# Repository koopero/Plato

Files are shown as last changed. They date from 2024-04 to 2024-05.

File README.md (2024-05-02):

# Project Plato

The goal is the creation of a full set of all 5 regular polyhedra, or Platonic Solids, using programmable LEDs and 3D printed plastic.

- Open-source hardware & software.
- AI-assisted programming and design practices.
- Iteratative & improvisational design processes.
- Parametric practical geometry. 
- PCB design using Kicad

# Subprojects

|Project|Description|Status|
|---|---|---|
|[Plato_A2](Plato_A2/README.md)|Triangular LED board|Awaiting manufacture|
|[Plato_A1](Plato_A1/README.md)|Triangular LED board|Failed testing|
|[Plato_B1](Plato_B1/README.md)|ESP32 control board|In-progress|
|[Plato_C1](Plato_C1/README.md)|Tetrahedron casing for Plato_A1|Success|

# Tooling

- Kicad
- Python
- ImageMagick
- OpenSCAD
- Blender

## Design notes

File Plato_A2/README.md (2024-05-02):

# Plato_A2

*Please note that this design has failed testing and should not be used.*

`Plato_A2` is a regular triangle, made of light and plastic, with a dimension of about an inch. This subassembly is meant as an experiment in:

|Spec|Value|Unit|
|----|-----|----|
|LED Count| 28 | WS2812B 2020|

# Process

- Iterate design scripts from `Plato_A1` ( `Plato_A2_design.py` and `kicad_align_leds.py` )
  - Better LED orientation.
  - Export of holes and jumpers.
  - Placement of capacitors.
- Start a new project in Kicad
- Create schematic with all parts.
- Switch to PCB designer and import generated file `Plato_A2_board.dxf` into edge cut layer.
- Copy and paste the script `kicad_align_leds.py` into Kicad's scripting console to position LEDs.
- Manually place bulk capacitors and resistor.
- Draw routes to connect all components, using vias beneath LEDs.
- Create wicked silkscreen for front.
  - Create `art/Plato_A2_Art.png` in Gimp
  - Import png to Inkscape
  - *Trace Bitmap* with *Color Quantization*
  - *Path / Break Apart*
  - Delete image and background shape
  - Export to `art/Plato_A2_Art.dxf`
  - Import to kicad silkscreen layer.
  - Manually delete overlaps after DRC.
- Run DRC and fix problems.
- Use Kicad's Fabrication Toolkit plugin to aid in preparing the board for fabrication.
- Use [JLCPCB](https://jlcpcb.com/)'s online tools to order 5 copies of the board.

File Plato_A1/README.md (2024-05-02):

# Plato_A1

*Please note that this design has failed testing and should not be used.*

`Plato_A1` is a regular triangle, made of light and plastic, with a dimension of about an inch. This subassembly is meant as an experiment in:

- **Parametric Geometry** : The layout and dimensions of the PCB are defined in python.
- **Electronic Basics** : Learn Kicad by doing.
- **LED placement** : The triangular shape of the piece makes cartesian component alignment unfeasible. Therfore, the LEDs are align in a triagnular grid. Additionally, the LEDs are oriented towards the centre of the piece, for aesthetics and to diffuse potential chromatric anisotropy.

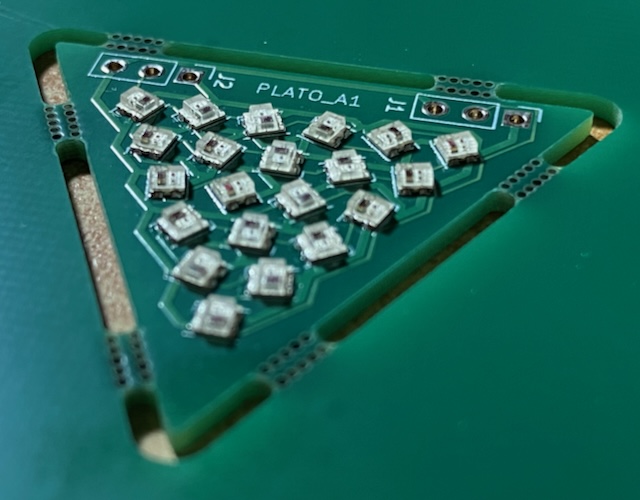
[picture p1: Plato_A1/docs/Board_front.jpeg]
Front of board

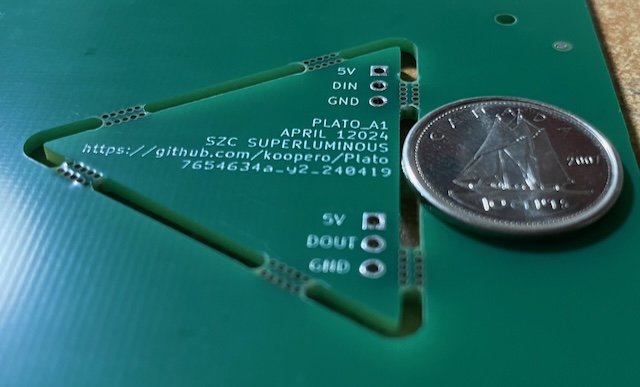
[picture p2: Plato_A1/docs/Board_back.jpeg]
Back of board


## Process

- Collaborate with ChapGPT & Copilot to prototype design generation scripts ( `Plato_A1_design.py` and `kicad_align_leds.py` )
- Tune parameters in design script to taste.
- Start a new project in Kicad
- Design circuit schematic in Kicad, consisting of 21 WS2812B 2020 LEDs and 2 3-pin jumper connectors. Ensure that all LEDs are sequentially named in the format `D1` to `D21`.
- Switch to PCB designer and import generated file `Plato_A1_board.dxf` into edge cut layer.
- Copy and paste the script `kicad_align_leds.py` into Kicad's scripting console to position LEDs.
- Manually place the jumper connectors.
- Draw routes to connect all components. Some LEDs are rotated in 90 degree increments for better connectivity.
- Add text and graphics the back silkscreen.
- Use Kicad's Fabrication Toolkit plugin to aid in preparing the board for fabrication.
- Use [JLCPCB](https://jlcpcb.com/)'s online tools to order 5 copies of the board.

## Result

Customer experience ordering from JLCPCB was exemplary. Representatives followed up for confirmation of the circuit's polarity (understandable given the non-traditional nature of the design).

Total cost for PCB manufacturing, assembly and shipping was about $100CAD. 

After unboxing, a quick test rig was produced, consisting of 3 jumper wires connected to a generic ESP32 Devkit V1, powered by USB. [WLED](https://install.wled.me/) was installed to produce a WS2811 signal.

Upon testing, the boards failed to maintain a coherent LED signal. About half the lamps will respond to a signal, but their performance is intermittent. By the end of the chain, the signal is lost completely.

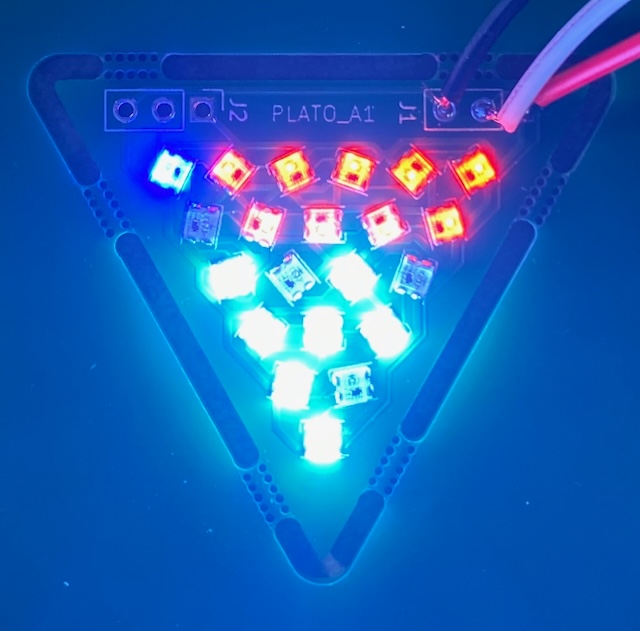
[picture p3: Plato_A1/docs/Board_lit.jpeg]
Front of board


## Lessons Learned

- PCB fabrication and assembly is a painless and relatively inexpensive process.
- Use power and ground planes in designing future PCBs.
- Decoupling capacitors and noise-supressing resistors will be necessary in subsequent designs.
- The chromatic anisotropy of WS2812B 2020 is much less pronounced than 5050 versions. Fun geometric placement will be de-prioritized in future version.
- Don't forget to choose the PCB colour when ordering!

## Next Steps

- Add through hole capacitors in attempt to stabilize boards.
- Assemble sample boards with Plato_C1 casing to demonstrate an illuminated, if uncontrolled, tetrahedron.
- Assemble content pertaining to creation of object.
- Research reference designs for WS2812B 2020 circuit boards.
- Design `Plato_A2` with similar dimensions and specifications, incorporating better electronic practices.

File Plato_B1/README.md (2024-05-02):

# Features

- ESP32-WROOM-32 Dual Core
- 

*After years of stringing together ESP32 Devkits, on breadboards and in boxes, I have decided to build.**

- MPU6050 accelerometer & gyro with independant i2c bus. 
- MicroUSB programming port (no charging).
- 4x exposed GPIO pins, each with accompanying 5V, and GND.
- 4x WS2812B 2020 LEDs, acting as both status display and signal booster. 
- 4x LED pin sets, with power from 5V or VBAT.
- Beefy 2A 5V buck converter, intended to run from 2S+ battery.
- Connection for external power switch.
- 6 pin auxillary connector with power & i2c.

At the end of the board

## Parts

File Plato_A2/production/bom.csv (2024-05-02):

Designator | Footprint | Quantity | Value | LCSC Part #
C1, C10, C11, C12, C13, C14, C15, C16, C17, C18, C19, C2, C20, C21, C22, C23, C24, C25, C26, C27, C28, C3, C4, C5, C6, C7, C8, C9 | 0402 | 28 | 100nF | C1525
C29, C30, C31 | 0603 | 3 | 10uF | C96446
D1, D10, D11, D12, D13, D14, D15, D16, D17, D18, D19, D2, D20, D21, D22, D23, D24, D25, D26, D27, D28, D3, D4, D5, D6, D7, D8, D9 | Plato_WS2812B-2020 | 28 | WS2812B-2020 | C965555
R1 | 0402 | 1 | 330ohm | C25104

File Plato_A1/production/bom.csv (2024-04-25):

Designator | Footprint | Quantity | Value | LCSC Part #
D1, D10, D11, D12, D13, D14, D15, D16, D17, D18, D19, D2, D20, D21, D3, D4, D5, D6, D7, D8, D9 | LED_WS2812B-2020_PLCC4_2.0x2.0mm | 21 | WS2812B-2020

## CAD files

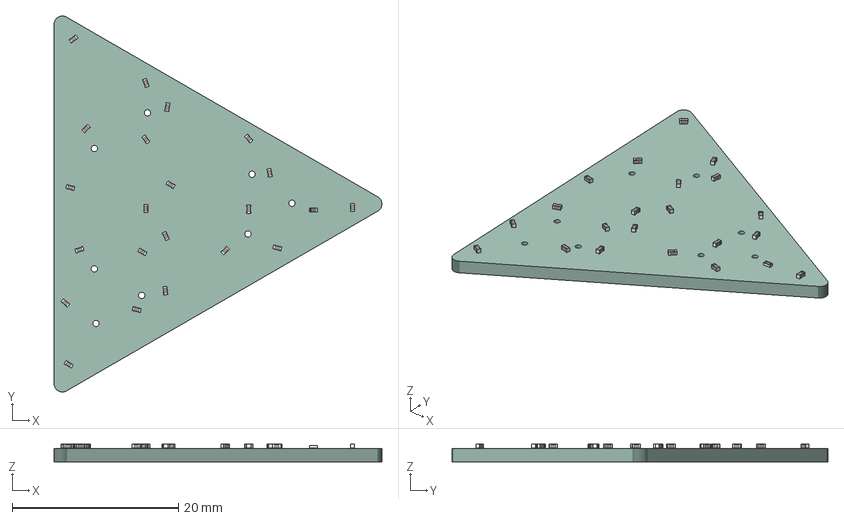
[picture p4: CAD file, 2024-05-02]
Plato_A1/output/Plato_A1.step
39.5 x 45.3 x 2.15 mm
R_0402_1005Metric
C_0402_1005Metric x 21
_autosave-Plato_A1_PCB

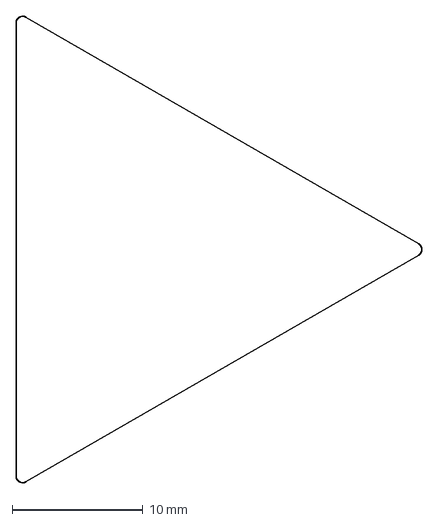
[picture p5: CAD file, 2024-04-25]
Plato_A1/Plato_A1_Board.dxf
31.0 x 35.6 mm

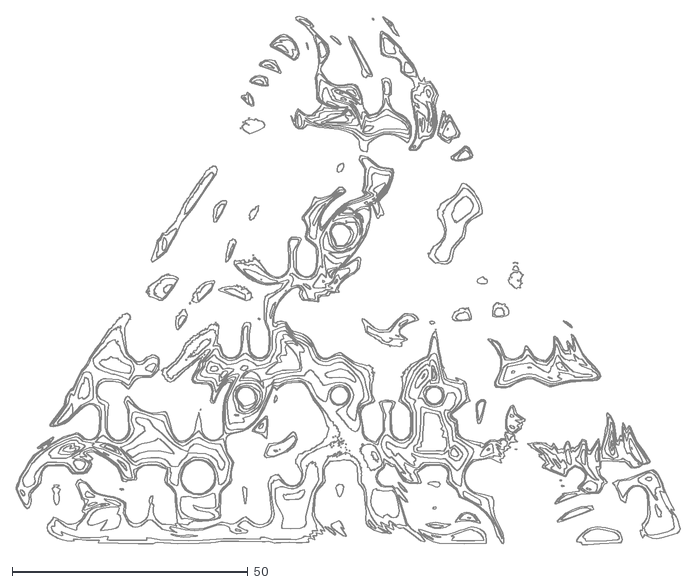
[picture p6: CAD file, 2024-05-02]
Plato_A2/art/Plato_A2_Art.dxf
140.7 x 111.9

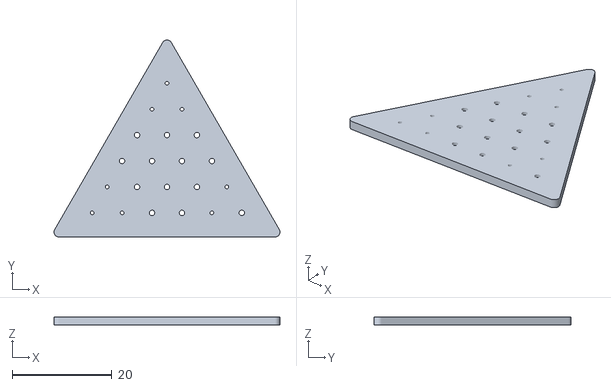
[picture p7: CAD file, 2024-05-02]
Plato_A2/output/Plato_A2_board.stl
45.3 x 39.5 x 1.60

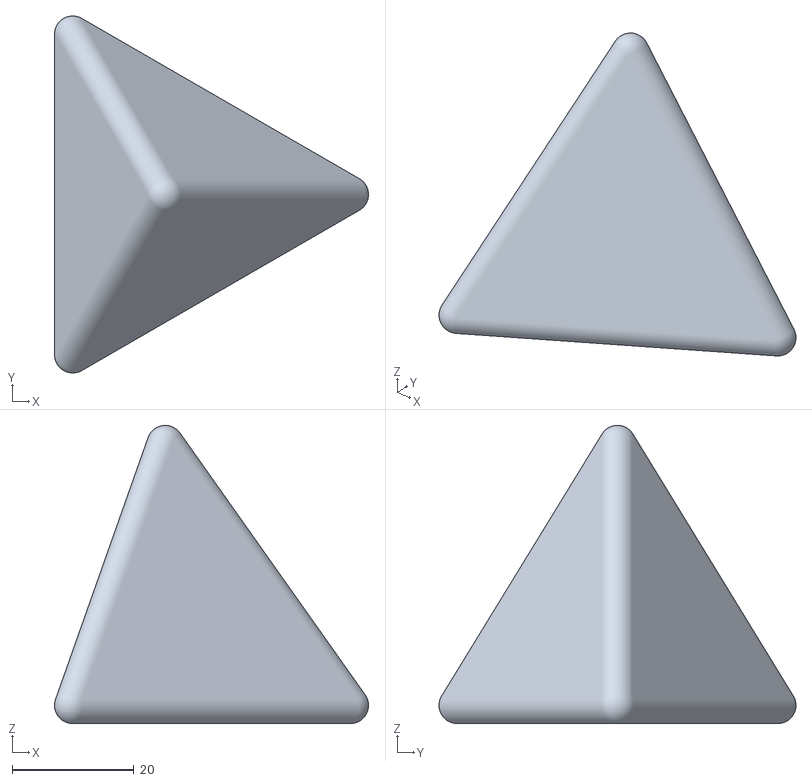
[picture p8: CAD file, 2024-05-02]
Plato_C1/Plato_C1_Tetra.stl
51.7 x 58.8 x 49.1

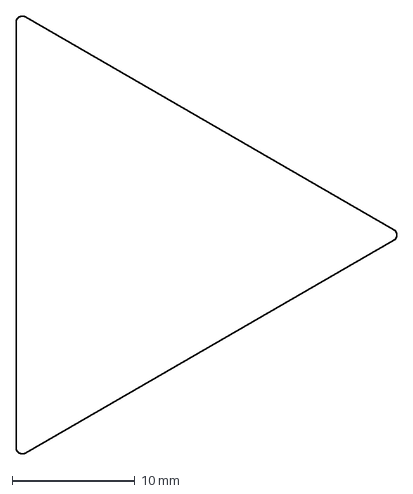
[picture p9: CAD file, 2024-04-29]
Plato_A1/output/Plato_A1_Board.dxf
31.0 x 35.6 mm

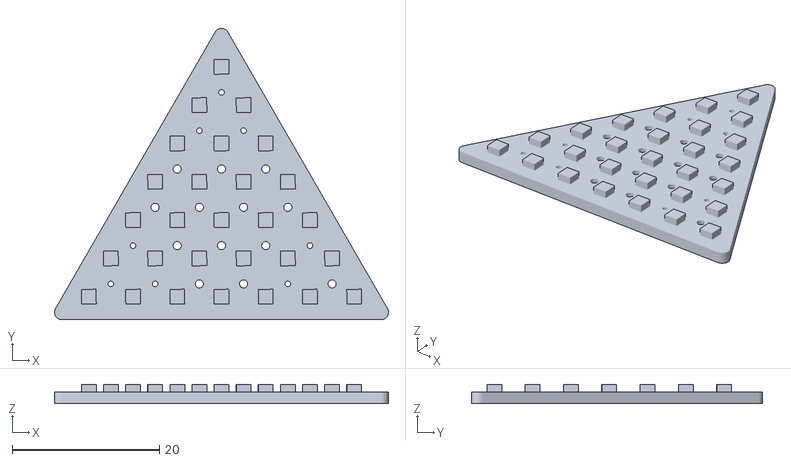
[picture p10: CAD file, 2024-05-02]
Plato_A2/output/Plato_A2.stl
45.3 x 39.5 x 2.60

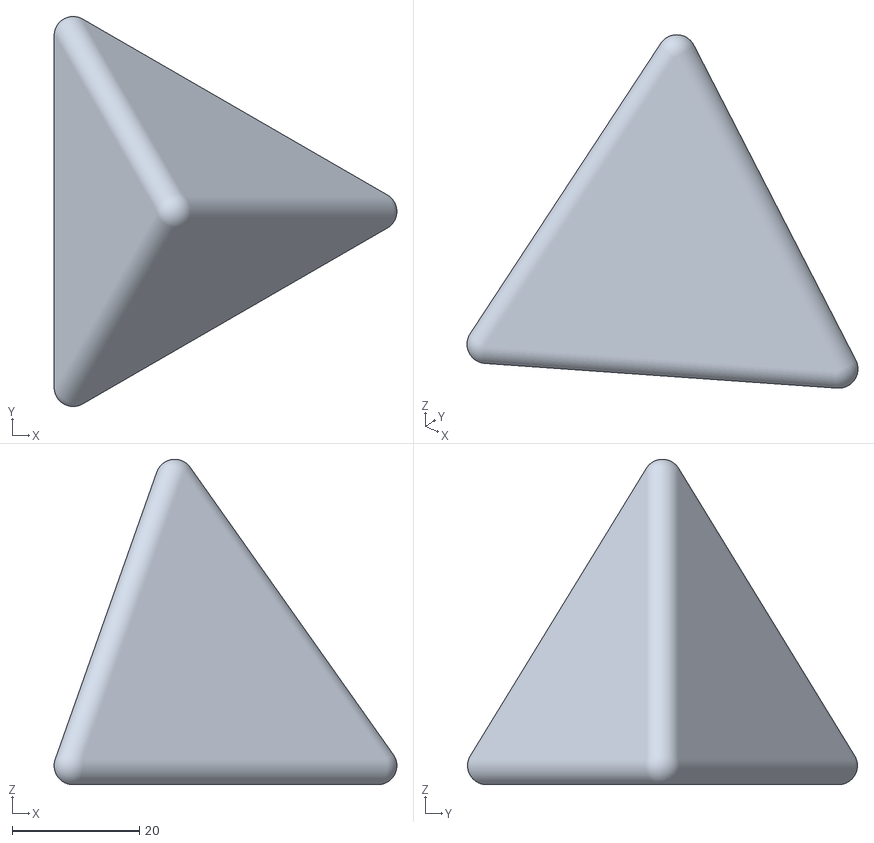
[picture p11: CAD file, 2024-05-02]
Plato_C1/Plato_C1.stl
53.9 x 61.3 x 51.2

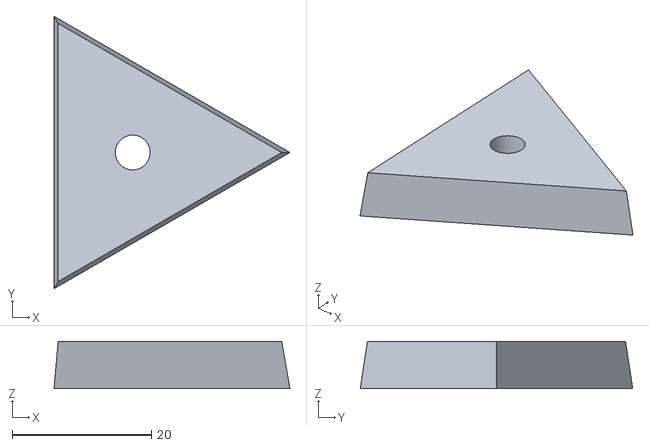
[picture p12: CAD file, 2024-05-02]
Plato_C1/Plato_C1_Cap.stl
33.9 x 39.1 x 6.82

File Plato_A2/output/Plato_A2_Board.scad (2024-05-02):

use <../library.scad>;
difference() {
   triangle_board( 27, 1, 1.6);
   hole(0.0, 17.320508075688775, 0.38);
   hole(-3.0, 12.12435565298214, 0.38);
   hole(3.0, 12.12435565298214, 0.38);
   hole(6.0, 6.928203230275509, 0.55);
   hole(0.0, 6.928203230275509, 0.55);
   hole(-6.0, 6.928203230275509, 0.55);
   hole(-9.0, 1.7320508075688772, 0.55);
   hole(-3.0, 1.7320508075688772, 0.55);
   hole(3.0, 1.7320508075688772, 0.55);
   hole(9.0, 1.7320508075688772, 0.55);
   hole(12.0, -3.464101615137755, 0.38);
   hole(6.0, -3.464101615137755, 0.55);
   hole(0.0, -3.464101615137755, 0.55);
   hole(-6.0, -3.464101615137755, 0.55);
   hole(-12.0, -3.464101615137755, 0.38);
   hole(-15.0, -8.660254037844387, 0.38);
   hole(-9.0, -8.660254037844387, 0.38);
   hole(-3.0, -8.660254037844387, 0.55);
   hole(3.0, -8.660254037844387, 0.55);
   hole(9.0, -8.660254037844387, 0.38);
   hole(15.0, -8.660254037844387, 0.55);
}

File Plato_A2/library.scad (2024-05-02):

$fs = 0.1;
$fa = 0.1;

module triangle_board( point_radius = 24, roundness = 1, extrusion = 1.6 ) {
    color([0.3,0.3,0.3])
    linear_extrude(height = extrusion, center = false)
    offset(r = roundness, chamfer = false) 
    offset(r = -roundness, chamfer = false) 
    polygon(points=[
        [-sin(60)*point_radius, -cos(60)* point_radius], // First vertex at origin
        [sin(60)*point_radius, -cos(60)* point_radius], // First vertex at origin
        [0, point_radius] // Third vertex at top center
    ]);
}

module hole(x, y, radius) {
    translate([x, y, 0])  // Move the cylinder to the (x, y) position
    cylinder(h = 100, r = radius, center = true);
}

module led(x, y, orientation, z = 1.6) {
    color("white", 1)
    translate([x, y, z+0.5])
    rotate([0, 0, orientation])
    cube([2, 2, 1], center = true);
}

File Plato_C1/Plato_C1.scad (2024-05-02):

// Define vertices of the regular tetrahedron
vertices = [
    [ 0,  0,  2],  // Vertex 0
    [-cos(60)*1,  -sin(60)*1, 0],  // Vertex 1
    [-cos(60)*1,  sin(60)*1, 0],  // Vertex 2
    [ 1,  0, 0]   // Vertex 3
];

// Define faces using the vertices
faces = [
    [0, 1, 2], // Face 1
    [0, 3, 1], // Face 2
    [0, 2, 3], // Face 3
    [1, 3, 2]  // Face 4
];



// Create the regular tetrahedron
polyhedron(points = vertices, faces = faces);

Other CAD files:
Plato_A2/output/Plato_A2.scad
Plato_A2/output/Plato_A2_Board.dxf

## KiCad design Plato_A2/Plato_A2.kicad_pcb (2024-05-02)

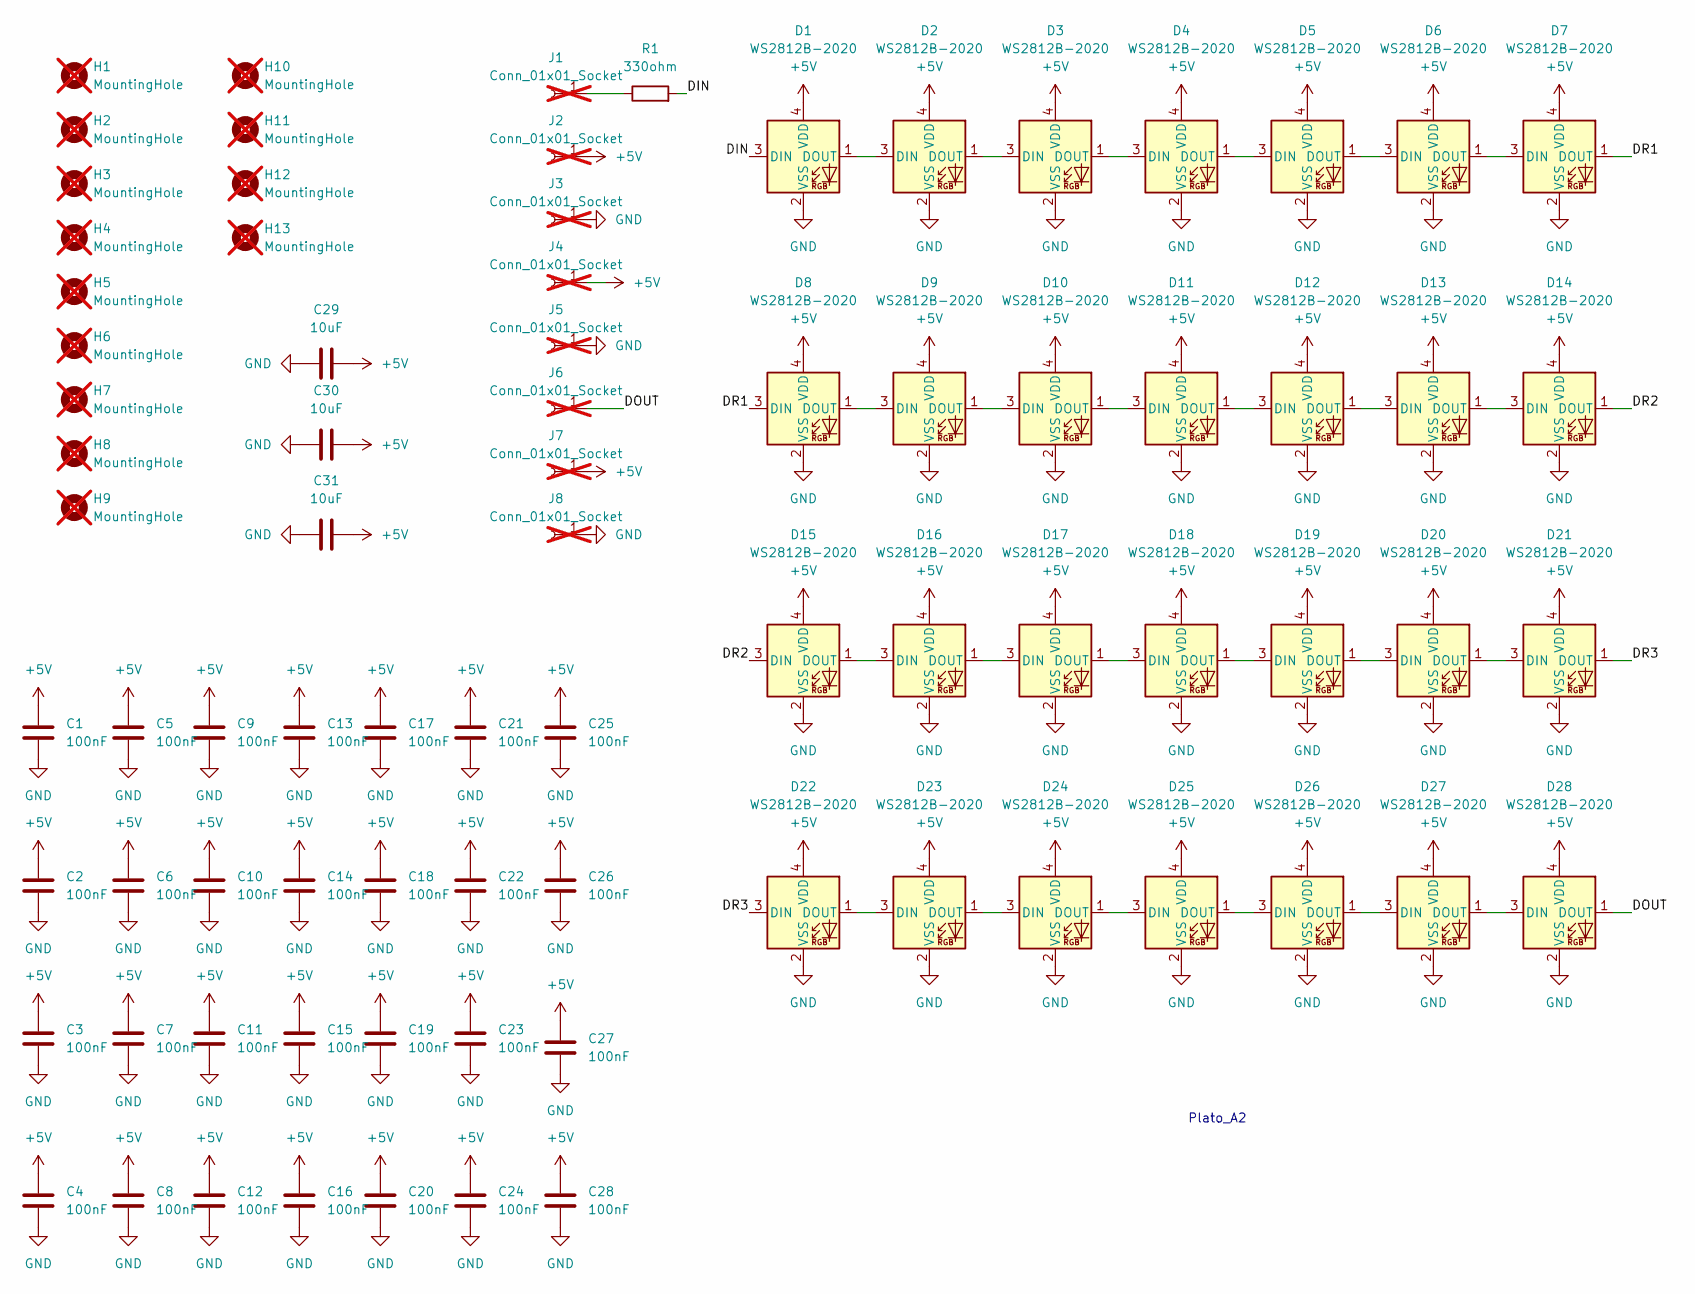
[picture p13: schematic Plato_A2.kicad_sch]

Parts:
C1, C2, C3, C4, C5, C6, C7, C8, C9, C10, C11, C12, C13, C14, C15, C16, C17, C18, C19, C20, C21, C22, C23, C24, C25, C26, C27, C28: 100nF; C_0402_1005Metric; LCSC C1525
C29, C30, C31: 10uF; C_0603_1608Metric; LCSC C96446
D1, D2, D3, D4, D5, D6, D7, D8, D9, D10, D11, D12, D13, D14, D15, D16, D17, D18, D19, D20, D21, D22, D23, D24, D25, D26, D27, D28: WS2812B-2020; Plato_WS2812B-2020; LCSC C965555
H1, H2, H3, H4, H5, H6, H7, H8, H9, H10, H11, H12, H13: MountingHole; MountingHoleM1; not fitted
J1, J6: Conn_01x01_Socket; DataHole; not fitted
J2, J3, J4, J5, J7, J8: Conn_01x01_Socket; PowerHole; not fitted
R1: 330ohm; R_0402_1005Metric; LCSC C25104

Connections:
+5V: C1.1, C2.1, C3.1, C4.1, C5.1, C6.1, C7.1, C8.1, C9.1, C10.1, C11.1, C12.1, C13.1, C14.1, C15.1, C16.1, C17.1, C18.1, C19.1, C20.1, C21.1, C22.1, C23.1, C24.1, C25.1, C26.1, C27.1, C28.1, C29.2, C30.2, C31.2, D1.4 (VDD), D2.4 (VDD), D3.4 (VDD), D4.4 (VDD), D5.4 (VDD), D6.4 (VDD), D7.4 (VDD), D8.4 (VDD), D9.4 (VDD), D10.4 (VDD), D11.4 (VDD), D12.4 (VDD), D13.4 (VDD), D14.4 (VDD), D15.4 (VDD), D16.4 (VDD), D17.4 (VDD), D18.4 (VDD), D19.4 (VDD), D20.4 (VDD), D21.4 (VDD), D22.4 (VDD), D23.4 (VDD), D24.4 (VDD), D25.4 (VDD), D26.4 (VDD), D27.4 (VDD), D28.4 (VDD), J2.1, J4.1, J7.1
/DIN: D1.3 (DIN), R1.2
/DOUT: D28.1 (DOUT), J6.1
/DR1: D7.1 (DOUT), D8.3 (DIN)
/DR2: D14.1 (DOUT), D15.3 (DIN)
/DR3: D21.1 (DOUT), D22.3 (DIN)
GND: C1.2, C2.2, C3.2, C4.2, C5.2, C6.2, C7.2, C8.2, C9.2, C10.2, C11.2, C12.2, C13.2, C14.2, C15.2, C16.2, C17.2, C18.2, C19.2, C20.2, C21.2, C22.2, C23.2, C24.2, C25.2, C26.2, C27.2, C28.2, C29.1, C30.1, C31.1, D1.2 (VSS), D2.2 (VSS), D3.2 (VSS), D4.2 (VSS), D5.2 (VSS), D6.2 (VSS), D7.2 (VSS), D8.2 (VSS), D9.2 (VSS), D10.2 (VSS), D11.2 (VSS), D12.2 (VSS), D13.2 (VSS), D14.2 (VSS), D15.2 (VSS), D16.2 (VSS), D17.2 (VSS), D18.2 (VSS), D19.2 (VSS), D20.2 (VSS), D21.2 (VSS), D22.2 (VSS), D23.2 (VSS), D24.2 (VSS), D25.2 (VSS), D26.2 (VSS), D27.2 (VSS), D28.2 (VSS), J3.1, J5.1, J8.1
unnamed: D1.1 (DOUT), D2.3 (DIN)
unnamed: D2.1 (DOUT), D3.3 (DIN)
unnamed: D3.1 (DOUT), D4.3 (DIN)
unnamed: D4.1 (DOUT), D5.3 (DIN)
unnamed: D5.1 (DOUT), D6.3 (DIN)
unnamed: D6.1 (DOUT), D7.3 (DIN)
unnamed: D8.1 (DOUT), D9.3 (DIN)
unnamed: D9.1 (DOUT), D10.3 (DIN)
unnamed: D10.1 (DOUT), D11.3 (DIN)
unnamed: D11.1 (DOUT), D12.3 (DIN)
unnamed: D12.1 (DOUT), D13.3 (DIN)
unnamed: D13.1 (DOUT), D14.3 (DIN)
unnamed: D15.1 (DOUT), D16.3 (DIN)
unnamed: D16.1 (DOUT), D17.3 (DIN)
unnamed: D17.1 (DOUT), D18.3 (DIN)
unnamed: D18.1 (DOUT), D19.3 (DIN)
unnamed: D19.1 (DOUT), D20.3 (DIN)
unnamed: D20.1 (DOUT), D21.3 (DIN)
unnamed: D22.1 (DOUT), D23.3 (DIN)
unnamed: D23.1 (DOUT), D24.3 (DIN)
unnamed: D24.1 (DOUT), D25.3 (DIN)
unnamed: D25.1 (DOUT), D26.3 (DIN)
unnamed: D26.1 (DOUT), D27.3 (DIN)
unnamed: D27.1 (DOUT), D28.3 (DIN)
unnamed: J1.1, R1.1

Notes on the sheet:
Plato_A2

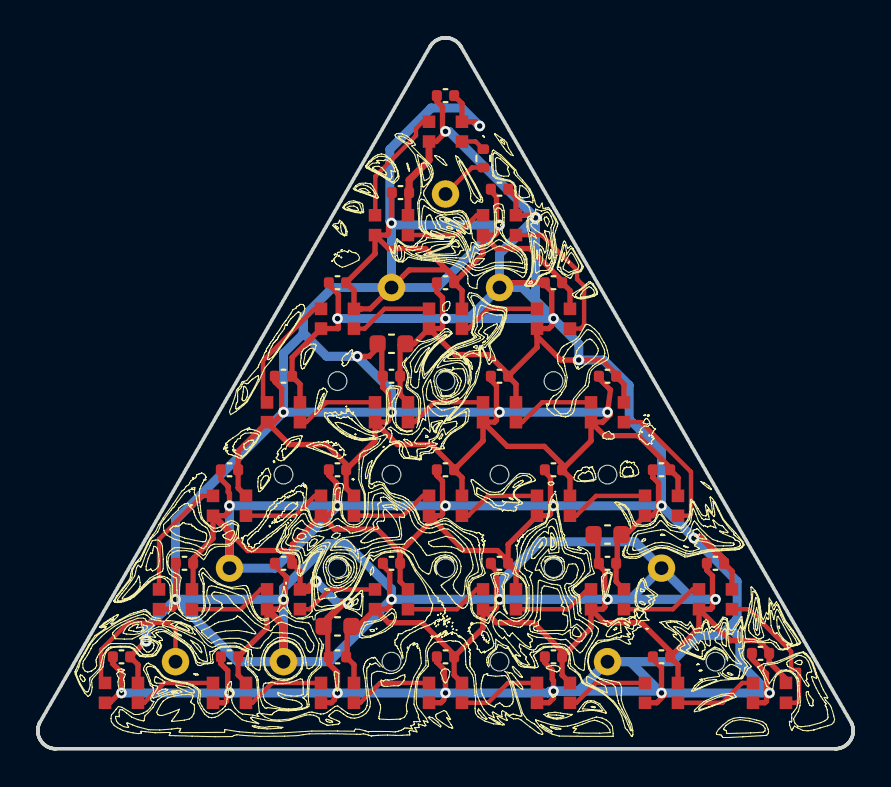
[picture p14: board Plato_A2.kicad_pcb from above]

Board: 2 copper layers, 45.3 x 39.5 mm, 81 parts (0 on the bottom side), 32 nets.

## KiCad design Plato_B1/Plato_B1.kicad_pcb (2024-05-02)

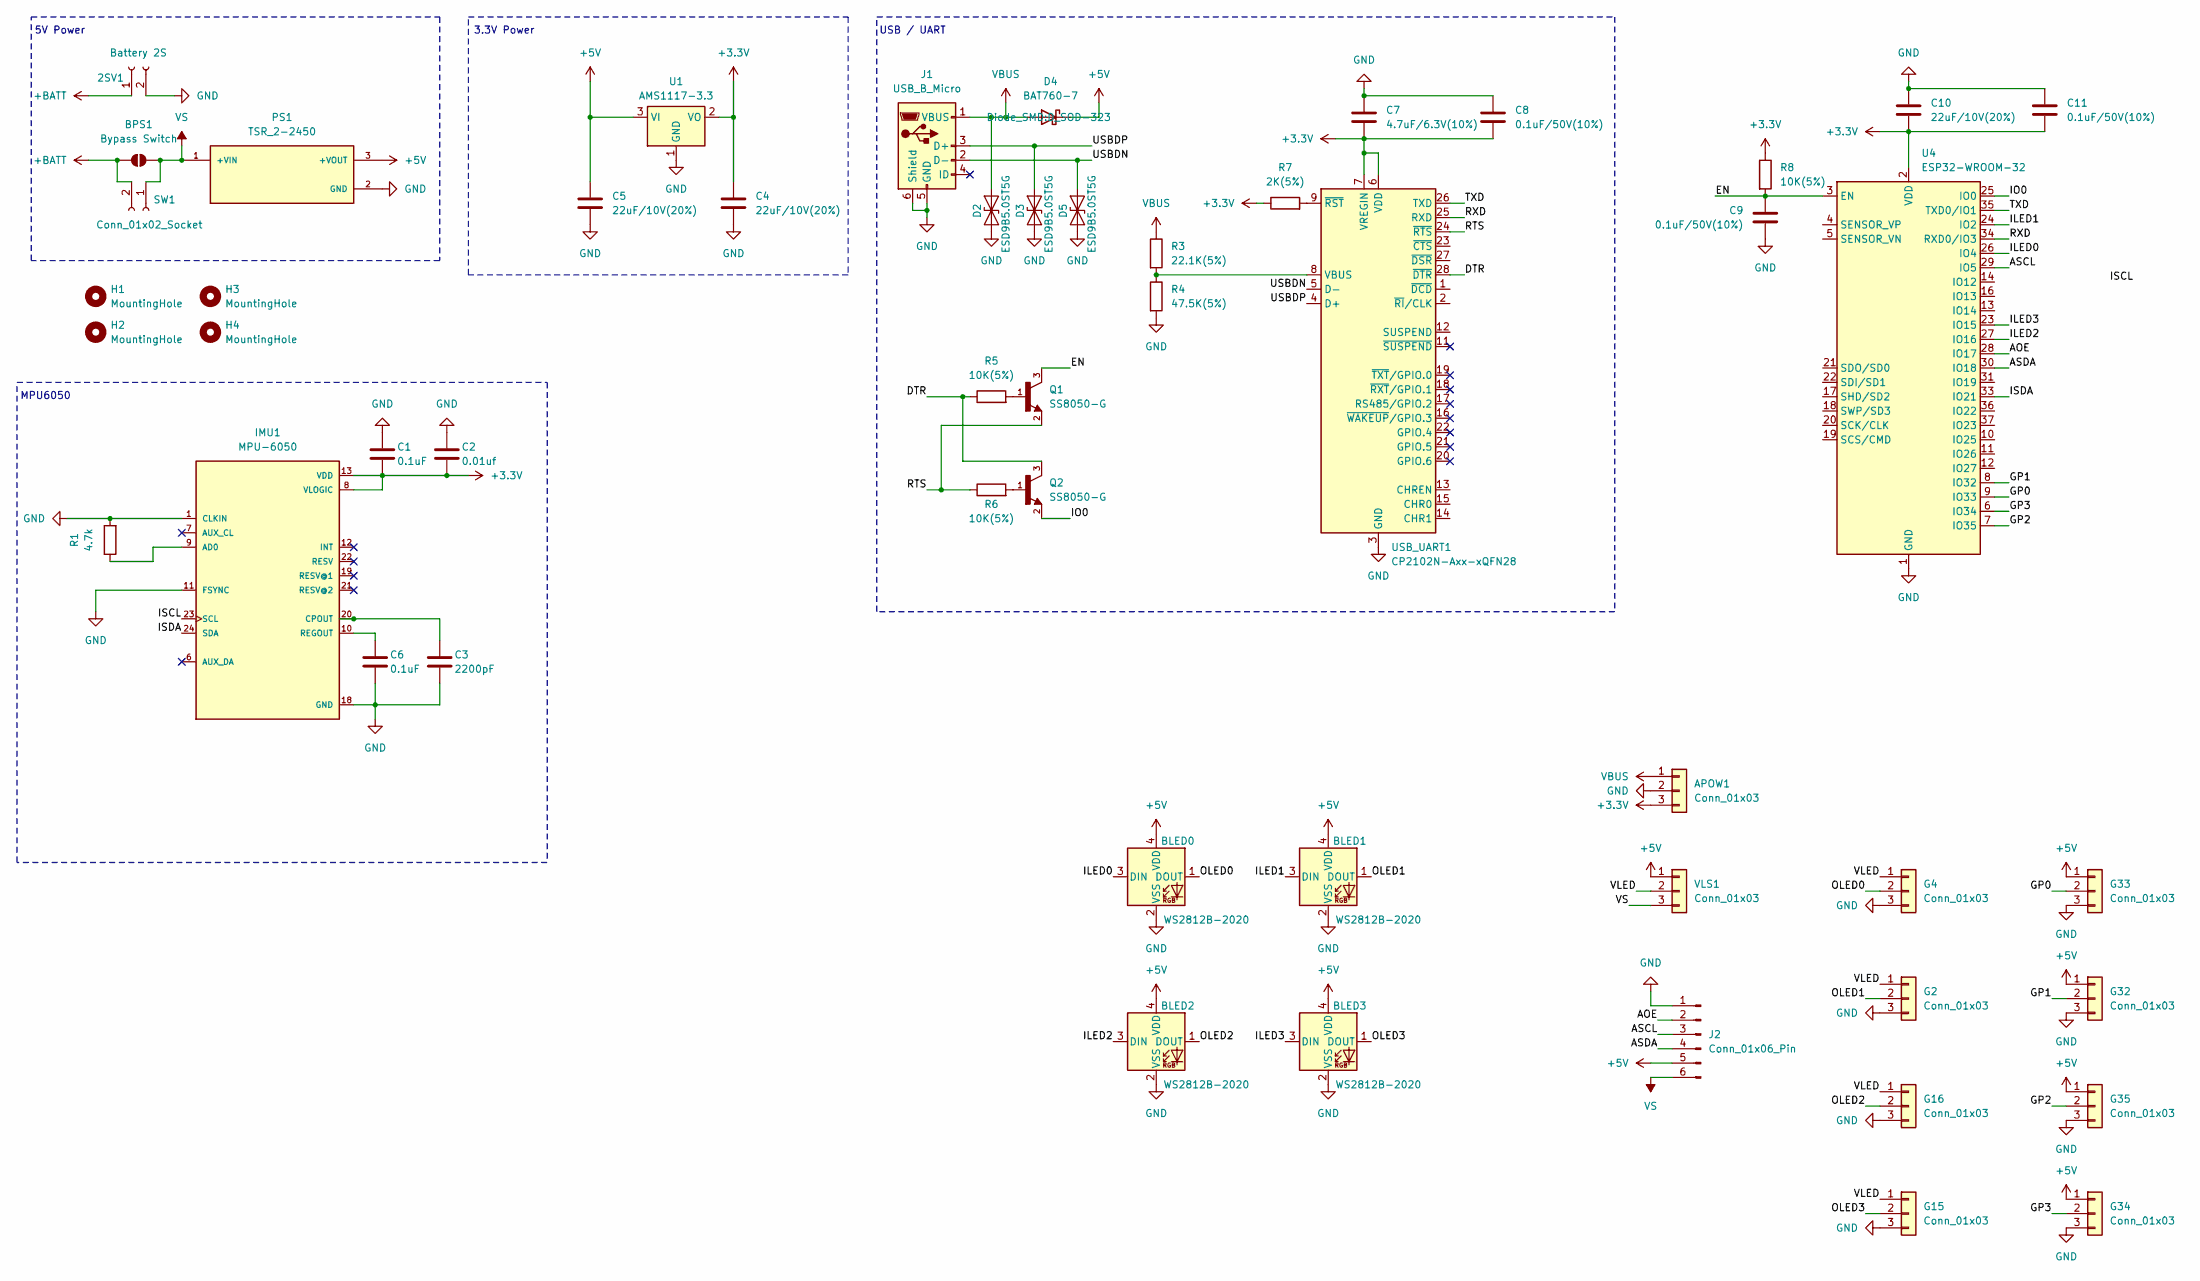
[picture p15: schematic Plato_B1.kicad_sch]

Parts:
2SV1: Battery 2S; PinHeader_1x02_P2.54mm_Vertical
APOW1: Conn_01x03; PinHeader_1x03_P2.54mm_Vertical
BLED0, BLED1, BLED2, BLED3: WS2812B-2020; LED_WS2812B-2020_PLCC4_2.0x2.0mm
BPS1: Bypass Switch; SolderJumper-2_P1.3mm_Open_TrianglePad1.0x1.5mm
C1, C6: 0.1uF; C_0603_1608Metric
C2: 0.01uf; C_0603_1608Metric
C3: 2200pF; LED_1210_3225Metric
C4, C5, C10: 22uF/10V(20%); C_1206_3216Metric
C7: 4.7uF/6.3V(10%); C_1206_3216Metric
C8, C9, C11: 0.1uF/50V(10%); C_0603_1608Metric
D2, D3, D5: ESD9B5.0ST5G; D_SOD-323
D4: BAT760-7; D_SOD-323
G2, G4, G15, G16, G32, G33, G34, G35: Conn_01x03; Centred_Pin1x3_2.54mm
H1, H2, H3, H4: MountingHole; MountingHole_2.2mm_M2
IMU1: MPU-6050; QFN50P400X400X95-24N; PARTREV 3.4
J1: USB_B_Micro; USB_Micro-B_Amphenol_10103594-0001LF_Horizontal
J2: Conn_01x06_Pin; PinHeader_1x06_P2.54mm_Vertical
PS1: TSR_2-2450; CONV_TSR_2-2450; PARTREV May 14, 2020
Q1, Q2: SS8050-G; SOT-23; PARTREV A
R1: 4.7k; R_0603_1608Metric
R3: 22.1K(5%); R_0603_1608Metric
R4: 47.5K(5%); R_0603_1608Metric
R5, R6, R8: 10K(5%); R_0603_1608Metric
R7: 2K(5%); R_0603_1608Metric
SW1: Conn_01x02_Socket; PinHeader_1x02_P2.54mm_Vertical
U1: AMS1117-3.3; SOT-223-3_TabPin2
U4: ESP32-WROOM-32
USB_UART1: CP2102N-Axx-xQFN28; QFN-28-1EP_5x5mm_P0.5mm_EP3.35x3.35mm
VLS1: Conn_01x03; PinHeader_1x03_P2.54mm_Vertical

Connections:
+3.3V: APOW1.3, C1.2, C2.2, C4.1, C7.2, C8.2, C10.2, C11.2, IMU1.8 (VLOGIC), IMU1.13 (VDD), R7.1, R8.1, U1.2 (VO), U4.2 (VDD), USB_UART1.6 (VDD), USB_UART1.7 (VREGIN)
+5V: BLED0.4 (VDD), BLED1.4 (VDD), BLED2.4 (VDD), BLED3.4 (VDD), C5.1, D4.1 (K), G32.1, G33.1, G34.1, G35.1, J2.5, PS1.3 (+VOUT), U1.3 (VI), VLS1.1
+BATT: 2SV1.1, BPS1.1 (A), SW1.2
/AOE: J2.2, U4.28 (IO17)
/ASCL: J2.3, U4.29 (IO5)
/ASDA: J2.4, U4.30 (IO18)
/DTR: Q2.3, R5.1, USB_UART1.28 (~DTR)
/EN: C9.1, Q1.3, R8.2, U4.3 (EN)
/GP0: G33.2, U4.9 (IO33)
/GP1: G32.2, U4.8 (IO32)
/GP2: G35.2, U4.7 (IO35)
/GP3: G34.2, U4.6 (IO34)
/ILED0: BLED0.3 (DIN), U4.26 (IO4)
/ILED1: BLED1.3 (DIN), U4.24 (IO2)
/ILED2: BLED2.3 (DIN), U4.27 (IO16)
/ILED3: BLED3.3 (DIN), U4.23 (IO15)
/IO0: Q2.2, U4.25 (IO0)
/ISCL: IMU1.23 (SCL)
/ISDA: IMU1.24 (SDA), U4.33 (IO21)
/OLED0: BLED0.1 (DOUT), G4.2
/OLED1: BLED1.1 (DOUT), G2.2
/OLED2: BLED2.1 (DOUT), G16.2
/OLED3: BLED3.1 (DOUT), G15.2
/RTS: Q1.2, R6.1, USB_UART1.24 (~RTS)
/RXD: U4.34 (RXD0/IO3), USB_UART1.25 (RXD)
/TXD: U4.35 (TXD0/IO1), USB_UART1.26 (TXD)
/USBDN: D5.2 (A2), J1.2 (D-), USB_UART1.5 (D-)
/USBDP: D3.2 (A2), J1.3 (D+), USB_UART1.4 (D+)
/VLED: G2.1, G4.1, G15.1, G16.1, VLS1.2
GND: 2SV1.2, APOW1.2, BLED0.2 (VSS), BLED1.2 (VSS), BLED2.2 (VSS), BLED3.2 (VSS), C1.1, C2.1, C3.2, C4.2, C5.2, C6.2, C7.1, C8.1, C9.2, C10.1, C11.1, D2.1 (A1), D3.1 (A1), D5.1 (A1), G2.3, G4.3, G15.3, G16.3, G32.3, G33.3, G34.3, G35.3, IMU1.1 (CLKIN), IMU1.11 (FSYNC), IMU1.18 (GND), J1.5 (GND), J1.6 (Shield), J2.1, PS1.2 (GND), R1.2, R4.2, U1.1 (GND), U4.1 (GND), U4.15 (GND), U4.38 (GND), U4.39 (GND), USB_UART1.3 (GND), USB_UART1.29 (GND)
unnamed: IMU1.9 (AD0), R1.1
unnamed: C3.1, IMU1.20 (CPOUT)
unnamed: C6.1, IMU1.10 (REGOUT)
unnamed: Q1.1, R5.2
unnamed: Q2.1, R6.2
unnamed: R3.2, R4.1, USB_UART1.8 (VBUS)
unnamed: R7.2, USB_UART1.9 (~RST)
VBUS: APOW1.1, D2.2 (A2), D4.2 (A), J1.1 (VBUS), R3.1
VS: BPS1.2 (B), J2.6, PS1.1 (+VIN), SW1.1, VLS1.3

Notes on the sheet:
USB / UART
5V Power
MPU6050
3.3V Power

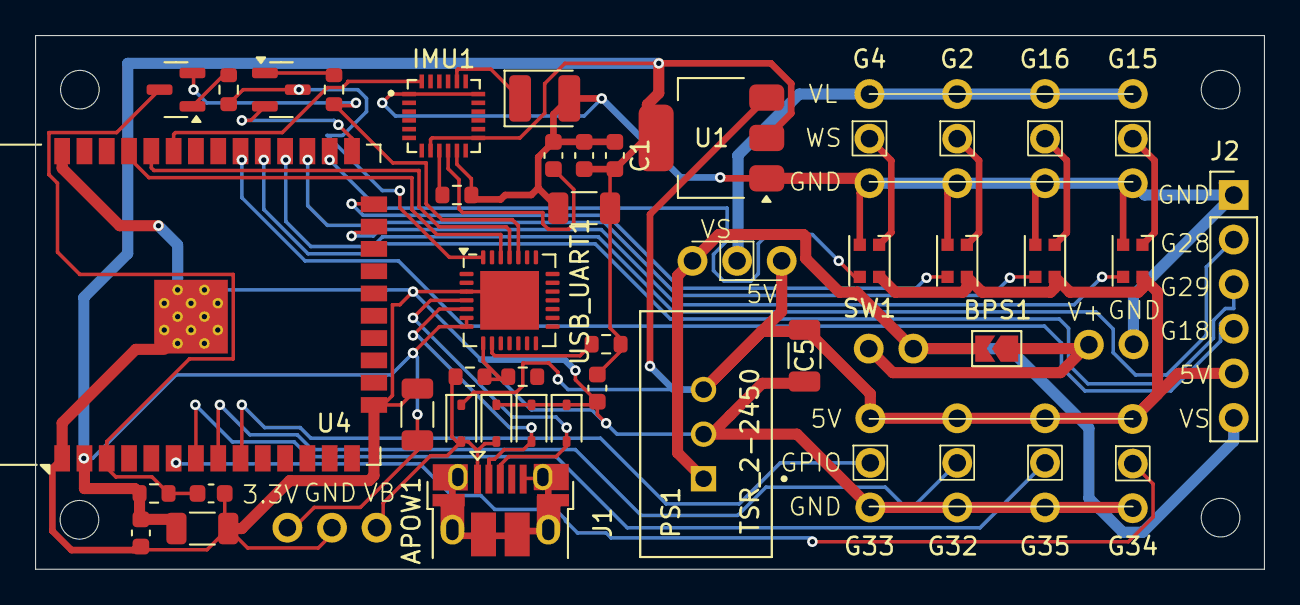
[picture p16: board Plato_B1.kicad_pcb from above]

Board: 2 copper layers, 70.0 x 30.4 mm, 52 parts (0 on the bottom side), 38 nets.

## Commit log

2024-04-25 Plato_A1 initial
    [Plato_A1.kicad_pcb, Plato_A1.kicad_sch, Plato_A1_Board.dxf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]
2024-04-29 Before ripping up Plato_A1
    [Plato_A1.kicad_sch, Plato_A1_Board.dxf, Plato_A1_LEDs.csv]
2024-05-02 Plato_B1 initial
    [Plato_B1.kicad_pcb, Plato_B1.kicad_sch]
2024-05-02 Plato_A2 initial
    [Plato_A2.kicad_pcb, Plato_A2.kicad_sch, Plato_A2.scad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]
2024-05-02 Plato_C1 initial test
    [Plato_C1.scad, Plato_C1.stl, Plato_C1_Cap.stl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]
2024-05-02 Abortative redesign
    [Plato_A1.kicad_pcb, Plato_A1.kicad_sch, Plato_A1.step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]
2024-05-02 Restore final product
    [Plato_A1.kicad_pcb, Plato_A1.kicad_sch, Plato_A1_Board.dxf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]
2024-05-02 Update design and output
    [Plato_A2.kicad_pcb, Plato_A2.stl, Plato_A2_Art.dxf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]
